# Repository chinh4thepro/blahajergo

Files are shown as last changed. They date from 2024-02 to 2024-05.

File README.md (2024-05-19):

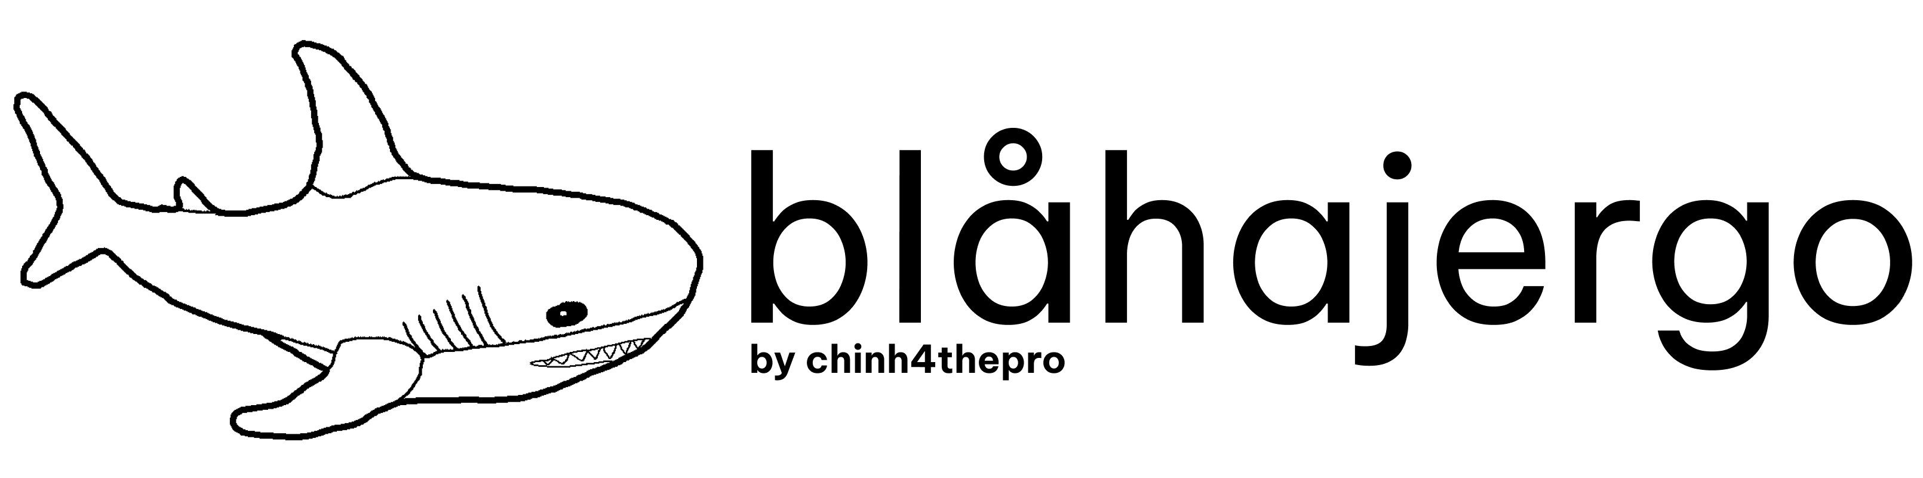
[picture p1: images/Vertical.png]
blahajergo vertical


## Hardware
Uses a Nice!Nano V2 (or any compatible microcontroller) as the MCU

Parts list:
- 56x SOD-123 (supports through holes too) 1N4148W diodes
- 56x Kailh 1350 Hotswap Sockets
- 56x Kailh choc v1 or v2 switches (v1's may be a little loose)
- 54x 1u choc keycaps
- 2x 1.5u choc keycaps
- 2x Nice!Nano V2 (sockets too)
- 2x 0.91in 128x32 SSD1306 OLED displays (sockets too)
- 2x 110mAh 301230 lithium batteries with PH 2.00mm connectors
- 2x Alps miniature SPDT switches
- 2x JST PH 2.00mm battery connectors
- 2x Panasonic EVQPUC buttons

## Software
Keymap based/inspired by FlatFootFox's (ImStuBTW) [TypeBoy MKII](https://github.com/ImStuBTW/typeboy_mkii)

Config can be found [here](https://github.com/chinh4thepro/zmk-config-blahajergo/tree/master)

## Design
Planned to have a 3d-printed case and acrylic case.

Traced blahaj image in courtesy of [Sheepy0125](https://github.com/sheepy0125)

## Progress
- [x] Design schematic - Done 2/10/2024
- [x] Name + Logo - Done 2/5/2024
- [x] Design PCB - Done 2/10/2024
- [x] Redesign PCB - Done 5/08/2024
- [x] Order PCB + Parts - Done 2/12/2024
- [x] Reorder PCB - Done 5/9/2024
- [x] Construct PCB - Done 5/17/2024
- [x] Port to ZMK - Done 2/27/2024
- [ ] Design 3d case
- [ ] Design acrylic case

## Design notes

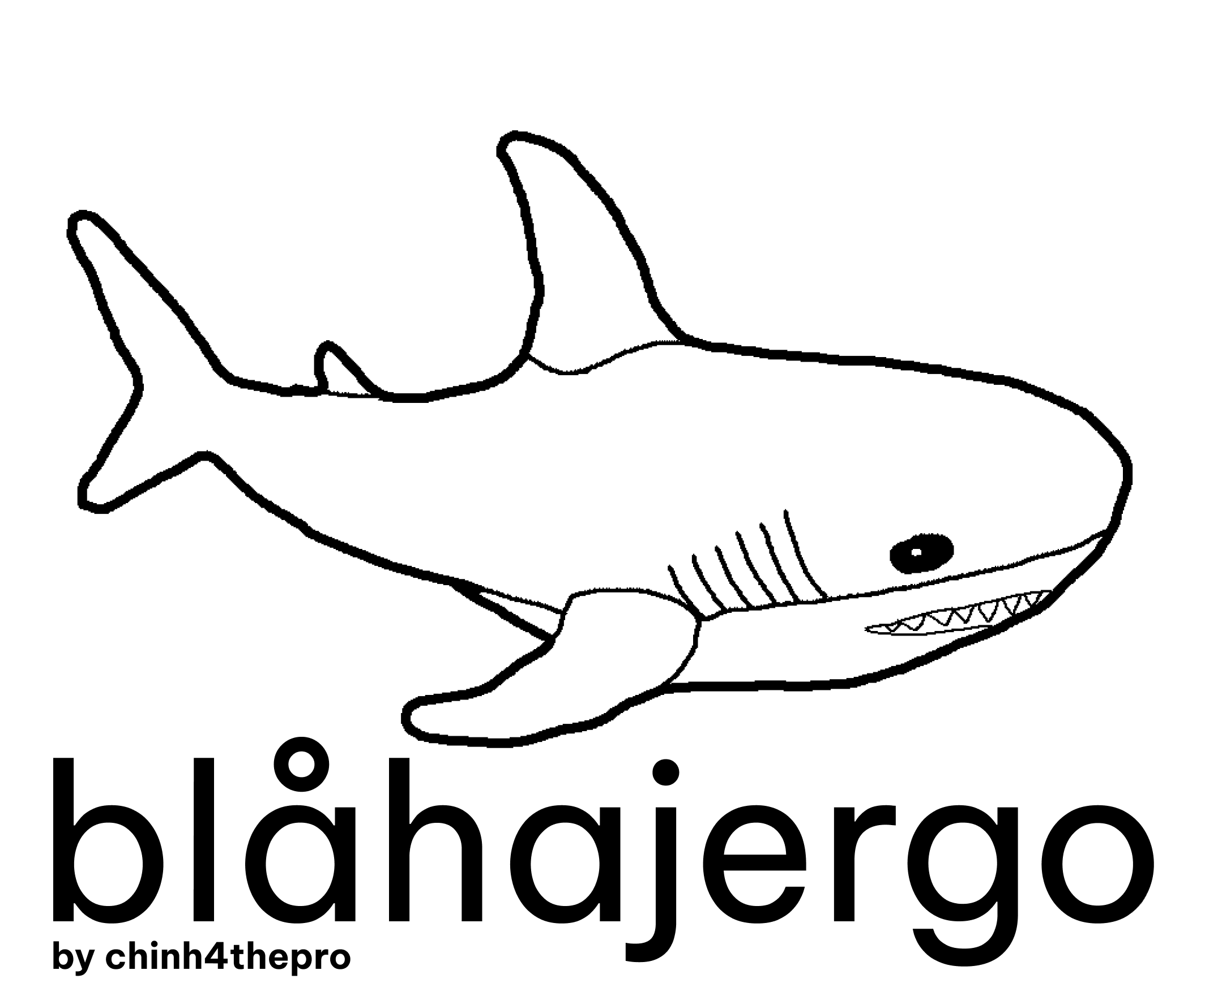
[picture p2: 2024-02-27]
images/Horizontal.png

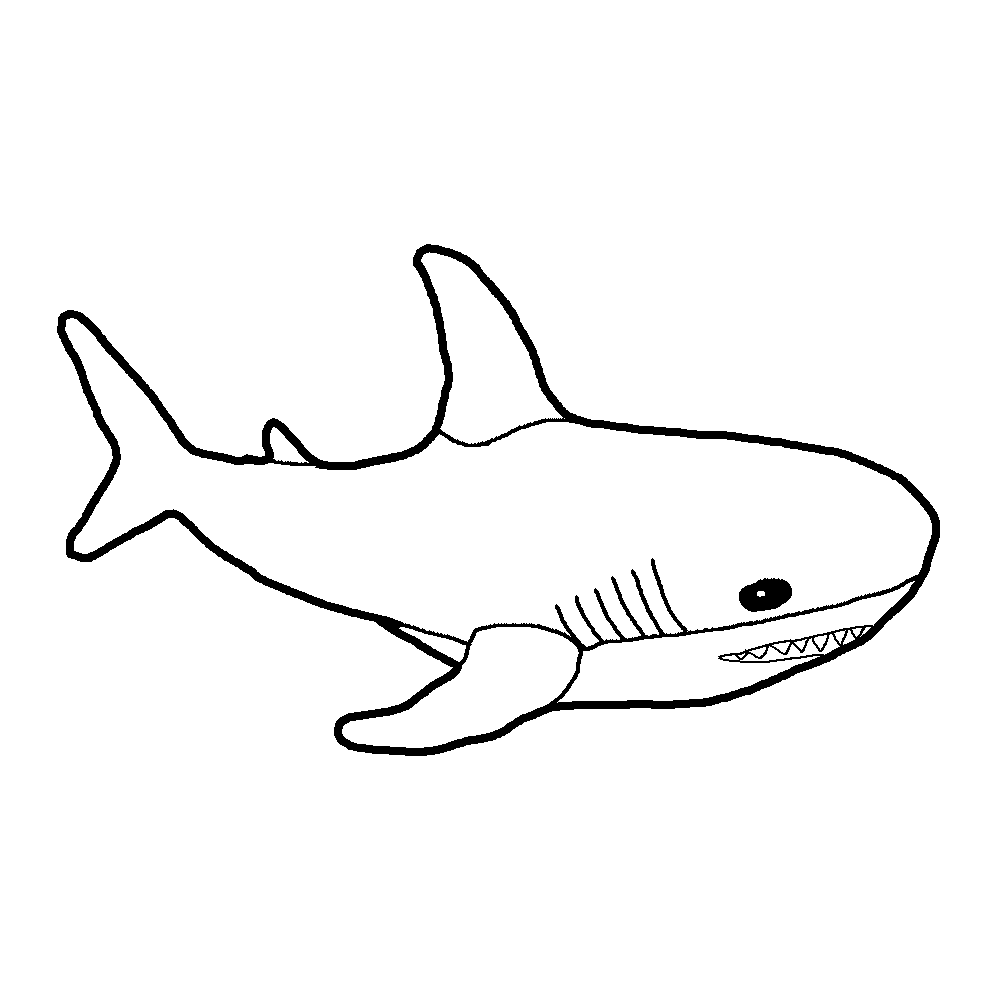
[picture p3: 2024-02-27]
images/blahaj_traced.png

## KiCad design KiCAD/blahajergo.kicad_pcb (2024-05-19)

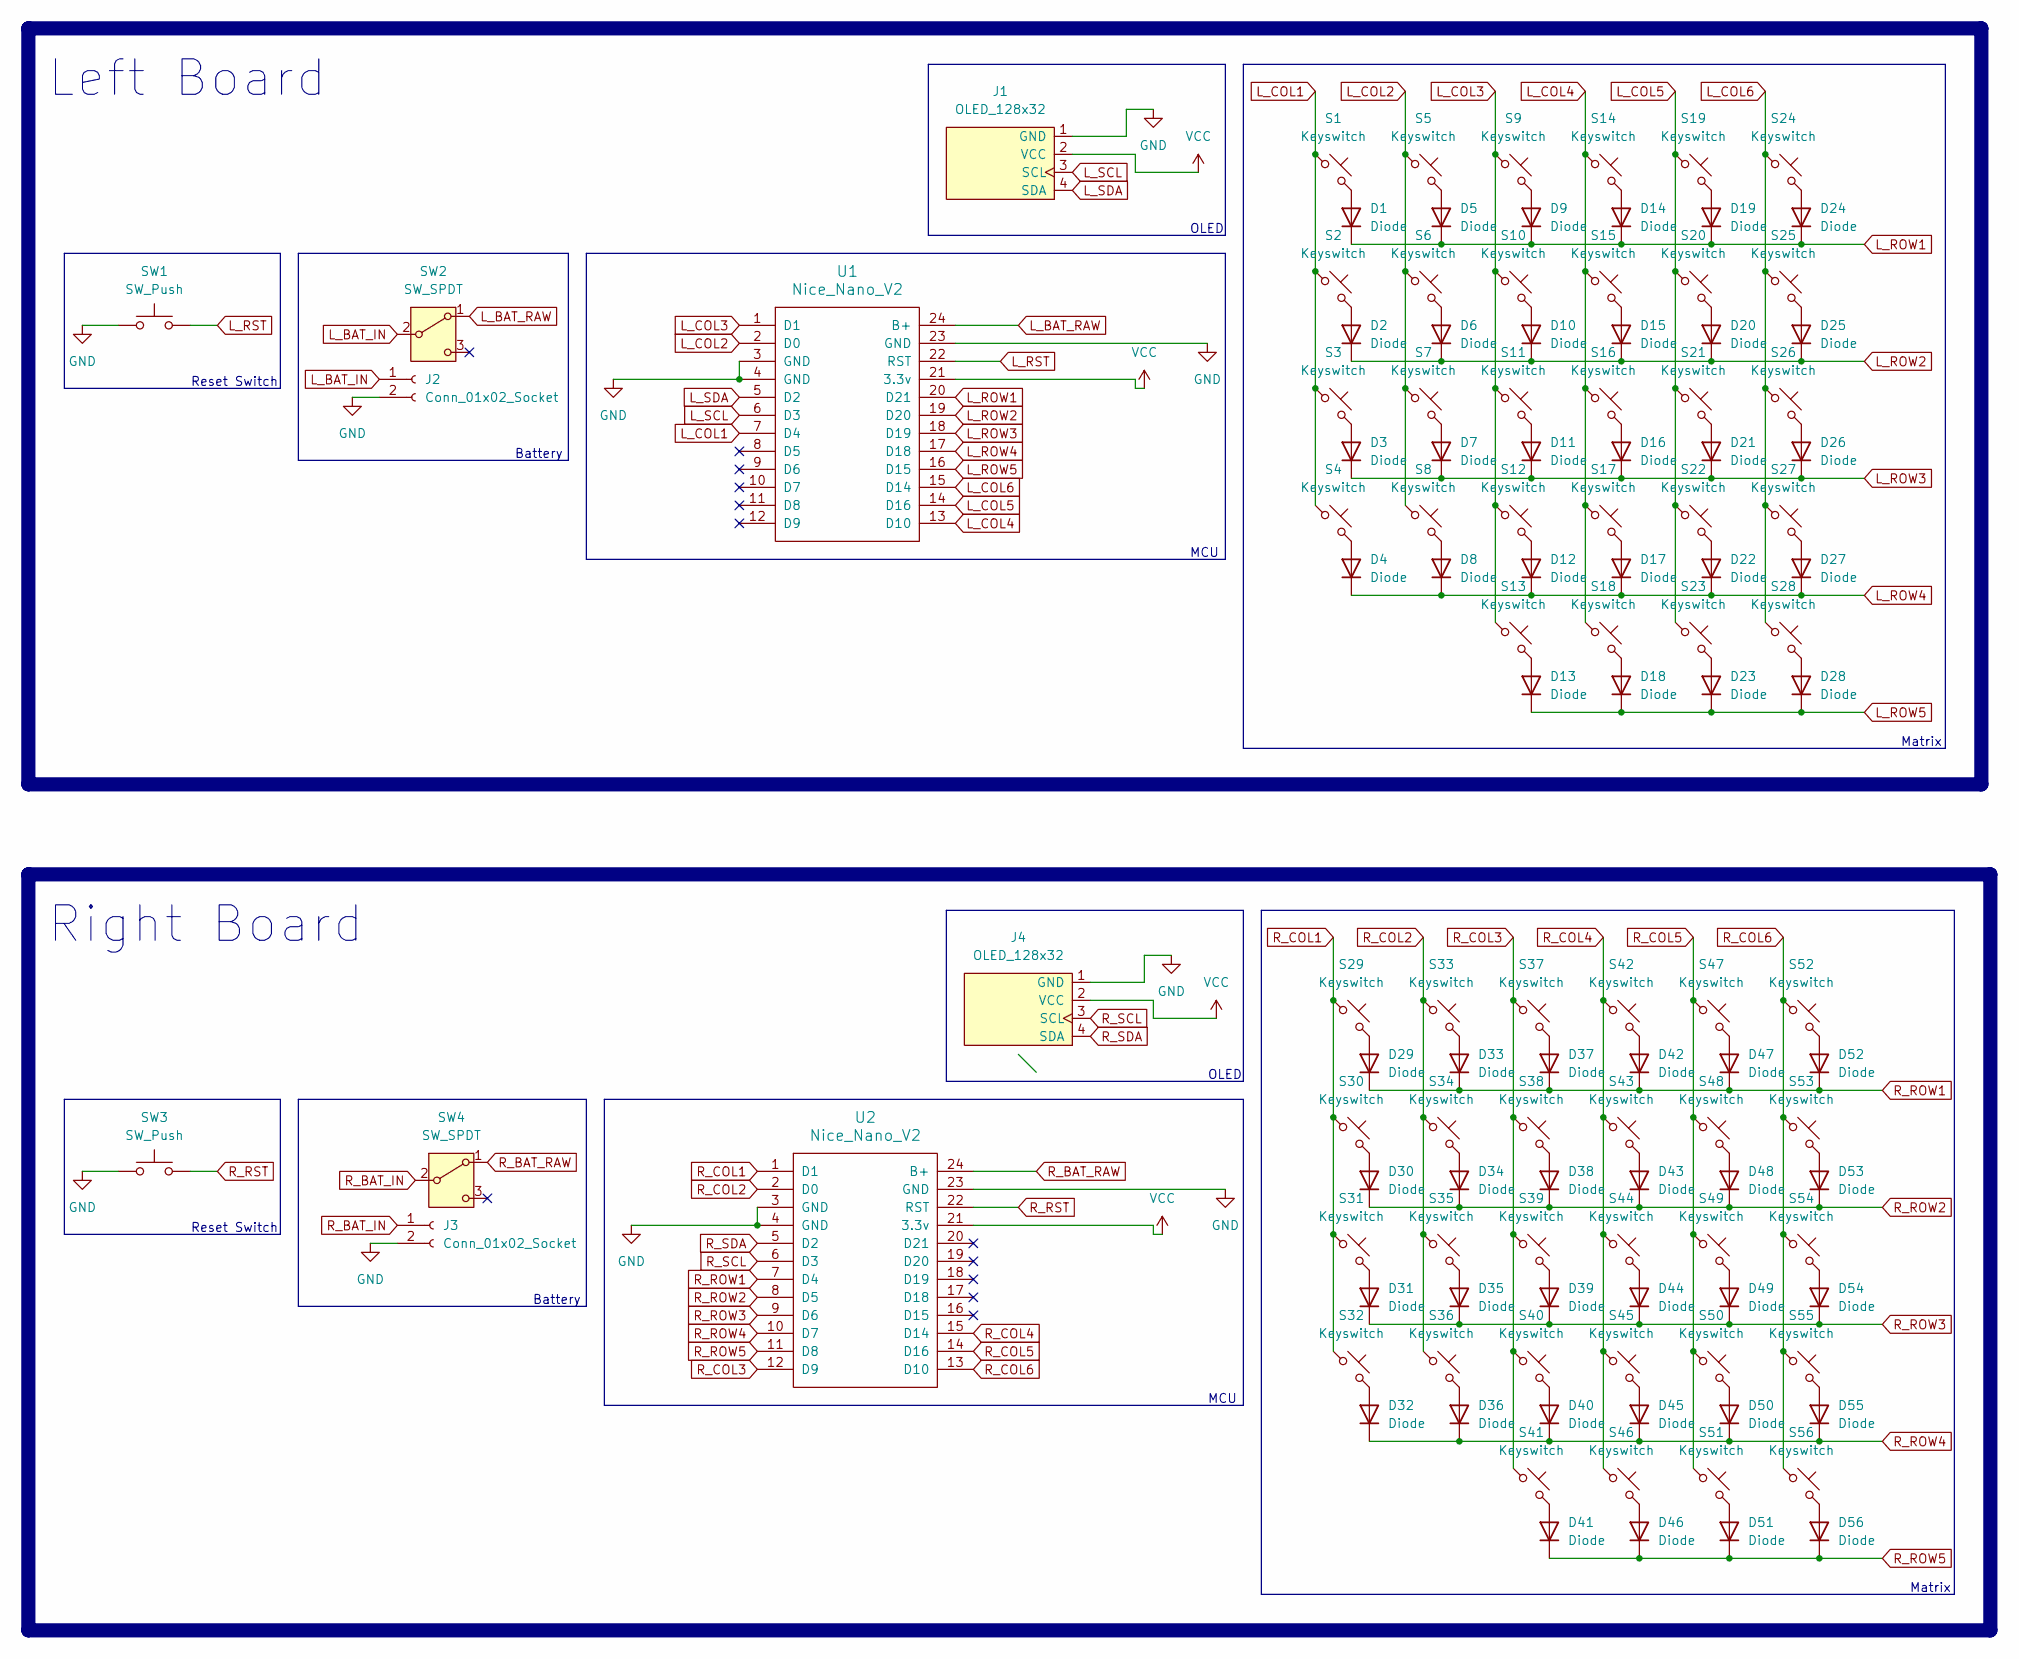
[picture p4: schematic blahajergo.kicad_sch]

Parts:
D1, D2, D3, D4, D5, D6, D7, D8, D9, D10, D11, D12, D13, D14, D15, D16, D17, D18, D19, D20, D21, D22, D23, D24, D25, D26, D27, D28, D29, D30, D31, D32, D33, D34, D35, D36, D37, D38, D39, D40, D41, D42, D43, D44, D45, D46, D47, D48, D49, D50, D51, D52, D53, D54, D55, D56: Diode; ComboDiode
J1, J4: OLED_128x32
J2, J3: Conn_01x02_Socket; JST_PH_S2B-PH-K_1x02_P2.00mm_Horizontal
S1, S2, S3, S4, S5, S6, S7, S8, S9, S10, S11, S12, S13, S14, S15, S16, S17, S18, S19, S20, S21, S22, S23, S24, S25, S26, S27, S28, S29, S30, S31, S32, S33, S34, S35, S36, S37, S38, S39, S40, S41, S42, S43, S44, S45, S46, S47, S48, S49, S50, S51, S52, S53, S54, S55, S56: Keyswitch; Hotswap_Choc_V1V2
SW1, SW3: SW_Push; Panasonic_EVQPUL_EVQPUC
SW2, SW4: SW_SPDT; SPDT_C128955
U1, U2: Nice_Nano_V2; Nice_Nano_V2_Flipped

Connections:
GND: J1.1 (GND), J2.2, J3.2, J4.1 (GND), SW1.1, SW3.1, U1.3 (GND), U1.4 (GND), U1.23 (GND), U2.3 (GND), U2.4 (GND), U2.23 (GND)
L_BAT_IN: J2.1, SW2.2 (B)
L_BAT_RAW: SW2.1 (A), U1.24 (B+)
L_COL1: S1.1, S2.1, S3.1, S4.1, U1.7 (D4)
L_COL2: S5.1, S6.1, S7.1, S8.1, U1.2 (D0)
L_COL3: S9.1, S10.1, S11.1, S12.1, S13.1, U1.1 (D1)
L_COL4: S14.1, S15.1, S16.1, S17.1, S18.1, U1.13 (D10)
L_COL5: S19.1, S20.1, S21.1, S22.1, S23.1, U1.14 (D16)
L_COL6: S24.1, S25.1, S26.1, S27.1, S28.1, U1.15 (D14)
L_ROW1: D1.1 (K), D5.1 (K), D9.1 (K), D14.1 (K), D19.1 (K), D24.1 (K), U1.20 (D21)
L_ROW2: D2.1 (K), D6.1 (K), D10.1 (K), D15.1 (K), D20.1 (K), D25.1 (K), U1.19 (D20)
L_ROW3: D3.1 (K), D7.1 (K), D11.1 (K), D16.1 (K), D21.1 (K), D26.1 (K), U1.18 (D19)
L_ROW4: D4.1 (K), D8.1 (K), D12.1 (K), D17.1 (K), D22.1 (K), D27.1 (K), U1.17 (D18)
L_ROW5: D13.1 (K), D18.1 (K), D23.1 (K), D28.1 (K), U1.16 (D15)
L_RST: SW1.2, U1.22 (RST)
L_SCL: J1.3 (SCL), U1.6 (D3)
L_SDA: J1.4 (SDA), U1.5 (D2)
unnamed: D1.2 (A), S1.2
unnamed: D2.2 (A), S2.2
unnamed: D3.2 (A), S3.2
unnamed: D4.2 (A), S4.2
unnamed: D5.2 (A), S5.2
unnamed: D6.2 (A), S6.2
unnamed: D7.2 (A), S7.2
unnamed: D8.2 (A), S8.2
unnamed: D9.2 (A), S9.2
unnamed: D10.2 (A), S10.2
unnamed: D11.2 (A), S11.2
unnamed: D12.2 (A), S12.2
unnamed: D13.2 (A), S13.2
unnamed: D14.2 (A), S14.2
unnamed: D15.2 (A), S15.2
unnamed: D16.2 (A), S16.2
unnamed: D17.2 (A), S17.2
unnamed: D18.2 (A), S18.2
unnamed: D19.2 (A), S19.2
unnamed: D20.2 (A), S20.2
unnamed: D21.2 (A), S21.2
unnamed: D22.2 (A), S22.2
unnamed: D23.2 (A), S23.2
unnamed: D24.2 (A), S24.2
unnamed: D25.2 (A), S25.2
unnamed: D26.2 (A), S26.2
unnamed: D27.2 (A), S27.2
unnamed: D28.2 (A), S28.2
unnamed: D29.2 (A), S29.2
unnamed: D30.2 (A), S30.2
unnamed: D31.2 (A), S31.2
unnamed: D32.2 (A), S32.2
unnamed: D33.2 (A), S33.2
unnamed: D34.2 (A), S34.2
unnamed: D35.2 (A), S35.2
unnamed: D36.2 (A), S36.2
unnamed: D37.2 (A), S37.2
unnamed: D38.2 (A), S38.2
unnamed: D39.2 (A), S39.2
unnamed: D40.2 (A), S40.2
unnamed: D41.2 (A), S41.2
unnamed: D42.2 (A), S42.2
unnamed: D43.2 (A), S43.2
unnamed: D44.2 (A), S44.2
unnamed: D45.2 (A), S45.2
unnamed: D46.2 (A), S46.2
unnamed: D47.2 (A), S47.2
unnamed: D48.2 (A), S48.2
unnamed: D49.2 (A), S49.2
unnamed: D50.2 (A), S50.2
unnamed: D51.2 (A), S51.2
unnamed: D52.2 (A), S52.2
unnamed: D53.2 (A), S53.2
unnamed: D54.2 (A), S54.2
unnamed: D55.2 (A), S55.2
unnamed: D56.2 (A), S56.2
R_BAT_IN: J3.1, SW4.2 (B)
R_BAT_RAW: SW4.1 (A), U2.24 (B+)
R_COL1: S29.1, S30.1, S31.1, S32.1, U2.1 (D1)
R_COL2: S33.1, S34.1, S35.1, S36.1, U2.2 (D0)
R_COL3: S37.1, S38.1, S39.1, S40.1, S41.1, U2.12 (D9)
R_COL4: S42.1, S43.1, S44.1, S45.1, S46.1, U2.15 (D14)
R_COL5: S47.1, S48.1, S49.1, S50.1, S51.1, U2.14 (D16)
R_COL6: S52.1, S53.1, S54.1, S55.1, S56.1, U2.13 (D10)
R_ROW1: D29.1 (K), D33.1 (K), D37.1 (K), D42.1 (K), D47.1 (K), D52.1 (K), U2.7 (D4)
R_ROW2: D30.1 (K), D34.1 (K), D38.1 (K), D43.1 (K), D48.1 (K), D53.1 (K), U2.8 (D5)
R_ROW3: D31.1 (K), D35.1 (K), D39.1 (K), D44.1 (K), D49.1 (K), D54.1 (K), U2.9 (D6)
R_ROW4: D32.1 (K), D36.1 (K), D40.1 (K), D45.1 (K), D50.1 (K), D55.1 (K), U2.10 (D7)
R_ROW5: D41.1 (K), D46.1 (K), D51.1 (K), D56.1 (K), U2.11 (D8)
R_RST: SW3.2, U2.22 (RST)
R_SCL: J4.3 (SCL), U2.6 (D3)
R_SDA: J4.4 (SDA), U2.5 (D2)
VCC: J1.2 (VCC), J4.2 (VCC), U1.21 (3.3v), U2.21 (3.3v)

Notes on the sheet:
OLED
Right Board
MCU
Battery
Reset Switch
Left Board
Matrix

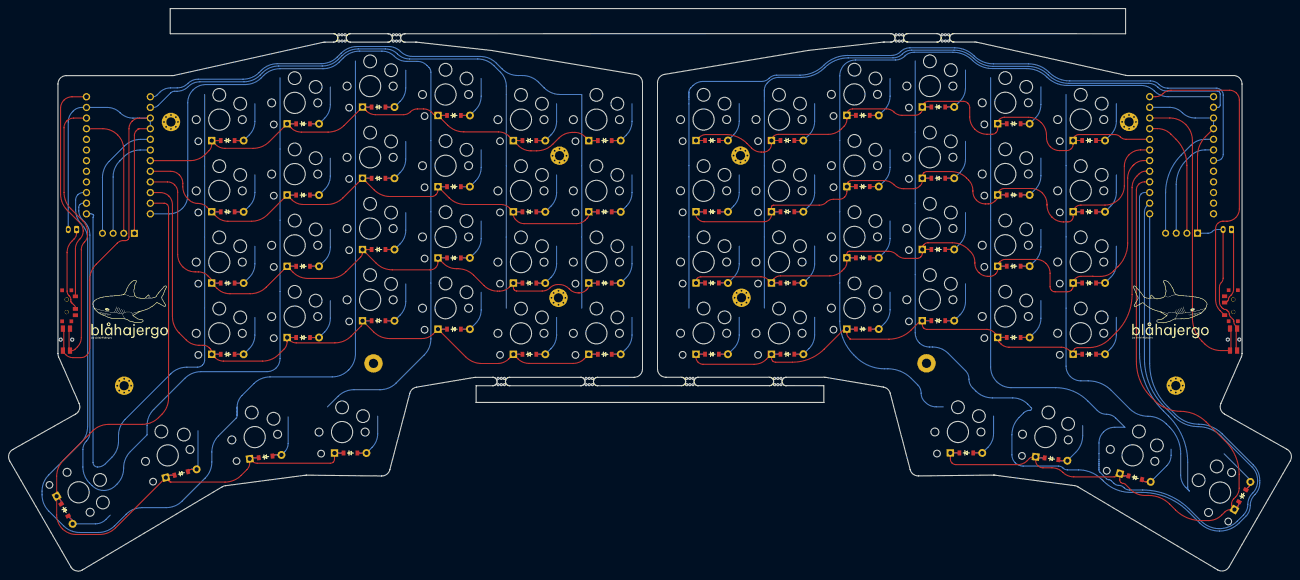
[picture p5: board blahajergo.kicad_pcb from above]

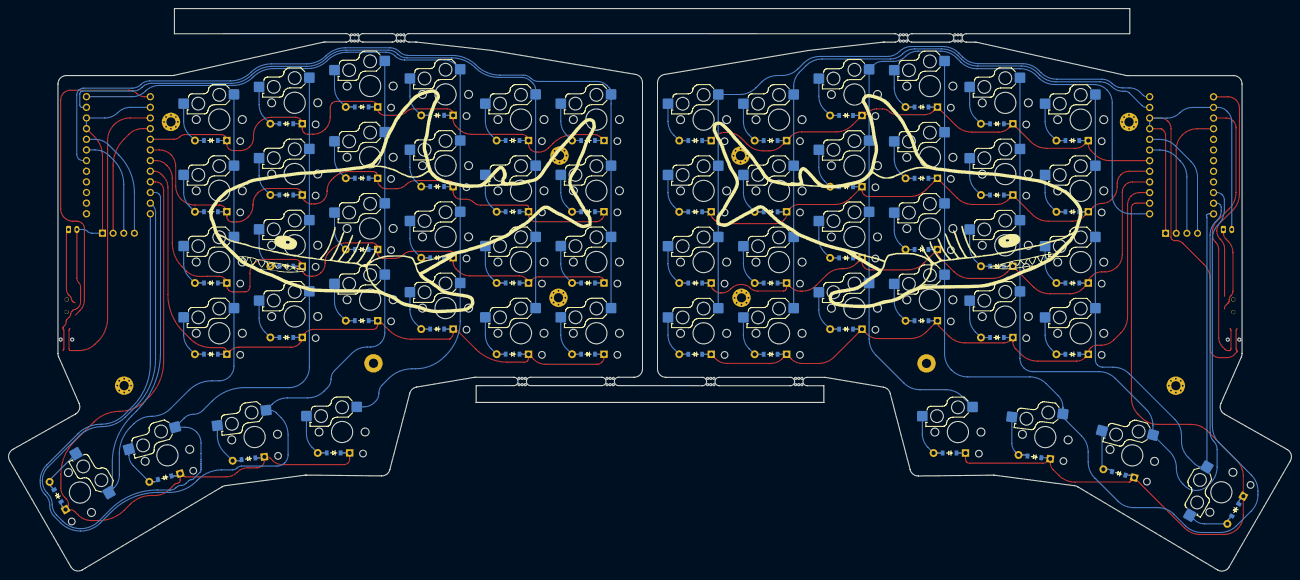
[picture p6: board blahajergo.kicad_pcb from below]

Board: 2 copper layers, 306.1 x 134.2 mm, 138 parts (6 on the bottom side), 90 nets.

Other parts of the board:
_6, _6#2, _6#3, _6#4, _6#5, _6#6, _6#7, _6#8: MountingHole_2.2mm_M2_Pad_Via
mouse-bite-2mm-slot, mouse-bite-2mm-slot#2, mouse-bite-2mm-slot#3, mouse-bite-2mm-slot#4, mouse-bite-2mm-slot#5, mouse-bite-2mm-slot#6, mouse-bite-2mm-slot#7, mouse-bite-2mm-slot#8: VAL**; mouse-bite-2mm-slot

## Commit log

2024-02-06 add pcbs
    [left_board.kicad_pcb, right_board.kicad_pcb]
2024-02-10 make shematic and condense into one file
    [blahajergo.kicad_pcb, blahajergo.kicad_sch, left_board.kicad_pcb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]
2024-02-11 add mousebites
    [BOM-blahajergo.csv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]
2024-02-26 remove text
    [blahajergo.kicad_pcb]
2024-02-27 REDO: Fix MCU orientation, add support for both choc v1 + v2, new graphics, and new reset switch
    [blahajergo.kicad_pcb, blahajergo.kicad_sch]
2024-04-04 use previous working pcb design
    [blahajergo.kicad_pcb]
2024-05-09 finally finish pcb redo
    [blahajergo.kicad_pcb, blahajergo.kicad_sch]
2024-05-09 production files
    [BOM-blahajergo.csv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]
2024-05-19 flip jst connector terminals
    [blahajergo.kicad_pcb]
